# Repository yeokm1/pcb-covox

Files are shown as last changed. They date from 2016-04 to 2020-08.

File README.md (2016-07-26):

# pcb-covox
A tiny sound card based on the Covox Speech Thing design. I have another design which adds on an LM386 amplifier which can be found [here](https://github.com/yeokm1/pcb-covox-amp/).

##PCB Design software and addons used

1. Eagle 7.5.0: I use Standard but Light should still be able to open/modify the files.

##Images
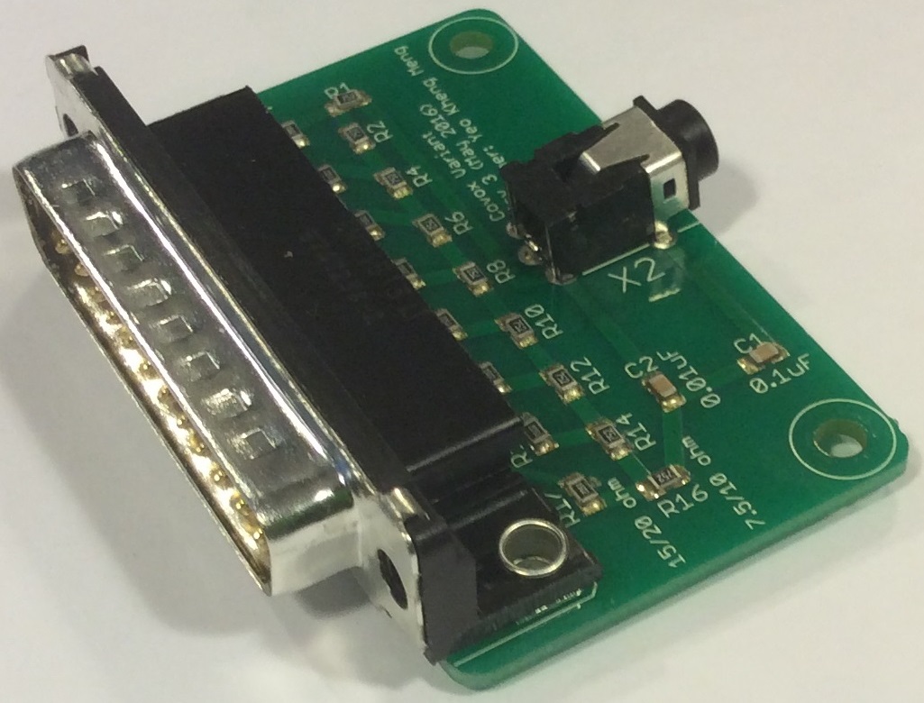
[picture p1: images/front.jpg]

This is a revision 3 board which has a bug in the mj2135 library which is a misaligned hole. I corrected this in Revision 4 but never actually fabricated that update.

Due to my oversight, only the DB25 pin 19 is grounded whearas the standard calls for pins 18-25 to be done so. You might need to modify the design if you face problems.

##Schematic drawings
Images are exported from Eagle at 600dpi.

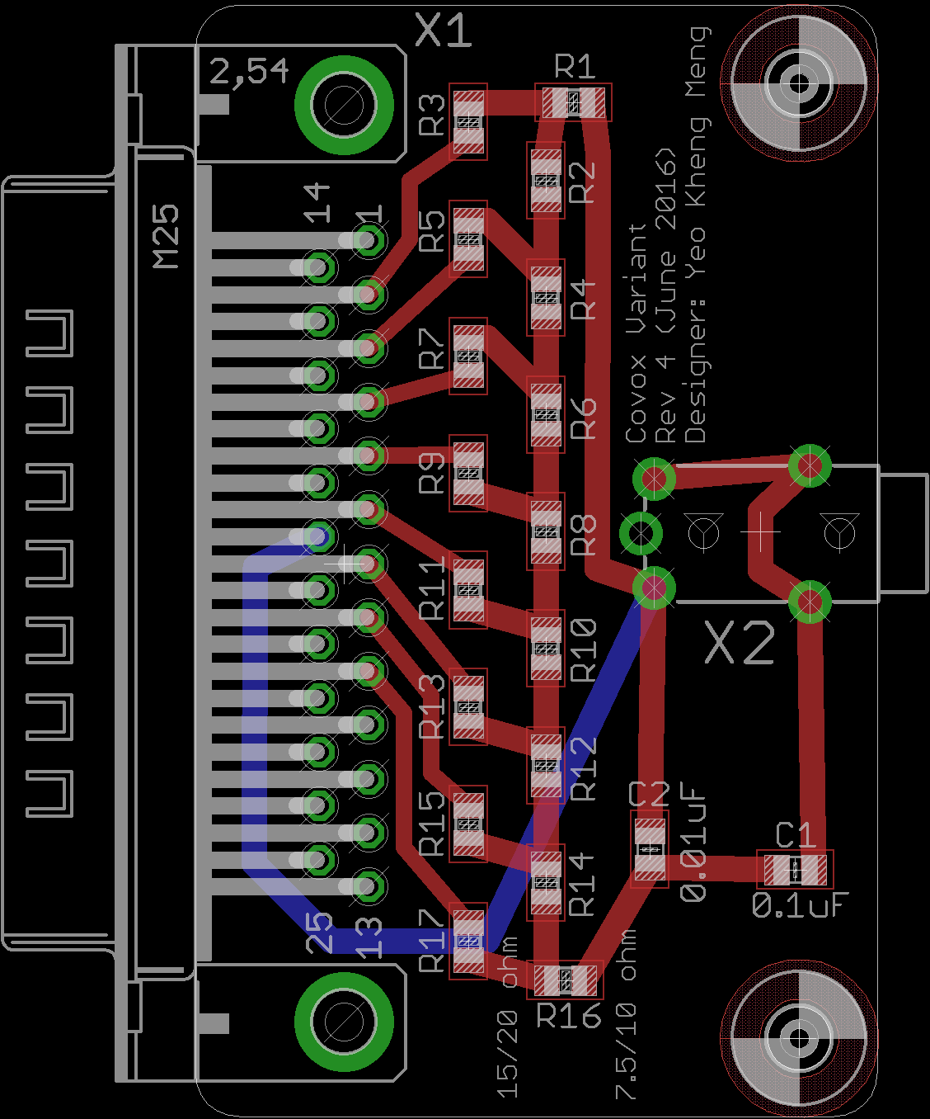
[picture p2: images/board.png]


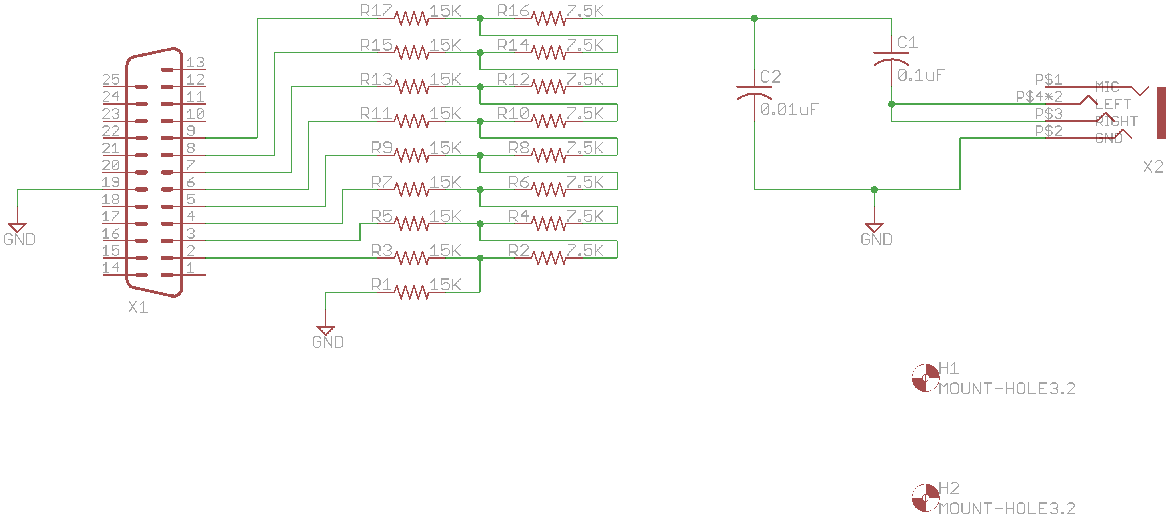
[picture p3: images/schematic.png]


##Parts required
Use Libreoffice to open [pcb-covox-bom.ods](pcb-covox-bom.ods)

##References
1. [Hardware implementation references](https://blog.frantovo.cz/c/307/DAC%20%28zvukov%C3%A1%20karta%29%20pro%20LPT%20port%20a.k.a.%20Covox)
2. [Design reference](http://kb.gr8bit.ru/KB0010/GR8BIT-KB0010-Adding-multimedia-capability-covox-device.html)
3. [MJ-2135 package obtained from coqui-dip](https://github.com/open-eie/coqui-dip)

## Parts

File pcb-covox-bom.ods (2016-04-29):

Parts | Value | Device | Package | Manufacturer | Part number | Qty | Unit Cost | Total Unit cost | Source webpage
X1 | DB-25 | Standard D Sub Connector, AMPLIMITE HD-20 Series, DB, Plug, 25, Steel Body, Through Hole | M-25HP | TE Connectivity | 5747238-2 | 1 | 5.07 | 5.07 | http://sg.element14.com/te-connectivity-amp/5747238-2/d-sub-connector-plug-25pos/dp/2452364
C2 | 0.01uF | SMD Multilayer Ceramic Capacitor, GRM Series | C0805 | Murata | GRM216R71H103JA01D | 1 | 0.065 | 0.065 | http://sg.element14.com/murata/grm216r71h103ja01d/cap-mlcc-x7r-10nf-50v-0805/dp/8820090
C1 | 0.1uF | SMD Multilayer Ceramic Capacitor, MCU Series | C0805 | Multicomp | MCU0805F104ZCT | 1 | 0.008 | 0.008 | http://sg.element14.com/multicomp/mcu0805f104zct/cap-mlcc-y5v-100nf-50v-0805/dp/9406409RL
R1, R3, R5, R7, R9, R11, R13, R15, R17 | 15K ohm, 0.5% | Surface Mount Chip Resistor, Thick Film, AEC-Q200 ERJ Series | R0805 | Panasonic Electronic Components | ERJ6RBD1502V | 9 | 0.047 | 0.423 | http://sg.element14.com/panasonic-electronic-components/erj6rbd1502v/res-thick-film-15k-0-5-0-1w-0805/dp/2380318
R2, R4, R6, R8, R10, R12, R14, R16 | 7.5K ohm, 0.5% | Thin Film, AEC-Q200 ERA Series | R0805 | Panasonic Electronic Components | ERA-6AED752V | 8 | 0.015 | 0.12 | http://sg.element14.com/panasonic-electronic-components/era-6aed752v/res-thin-film-7k5-0-5-0-125w-0805/dp/2407751
X2 | MJ-2135 | Phone Audio Connector, Socket, 3.5 mm, 4 Contacts | MJ-2135 | Pro Signal | MJ-2135 | 1 | 3.79 | 3.79 | http://sg.element14.com/pro-signal/mj-2135/connector-rca-jack-3-5mm-tht-4way/dp/1267377
- | HASL | PCB Fabrication | 5cm x 10cm | Elecrow | - | 1 | 7 | 7 | http://www.elecrow.com/5pcs-2-layer-pcb-p-1174.html
 |  |  |  |  |  |  | Subtotal | 16.476
 |  |  |  |  |  |  | GST 7% | 1.15332
 |  |  |  |  |  |  | Total (SGD) | 17.62932

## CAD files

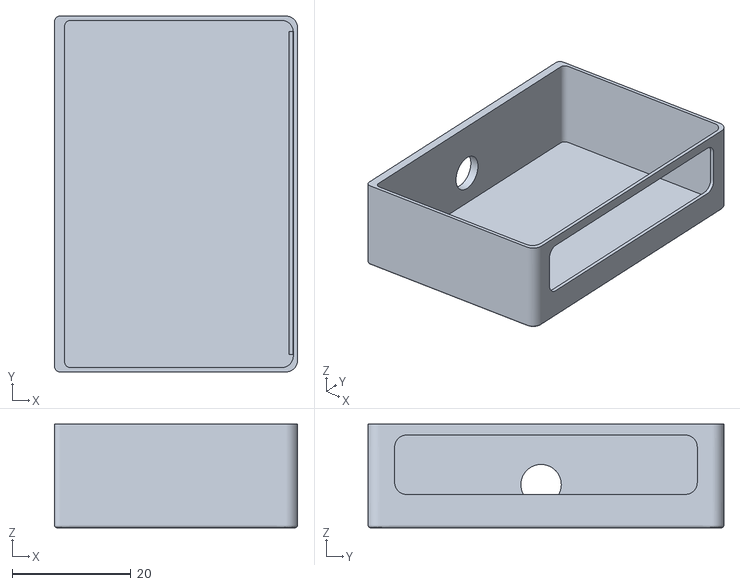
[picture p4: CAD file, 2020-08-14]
covox.stl
41.0 x 60.0 x 17.5

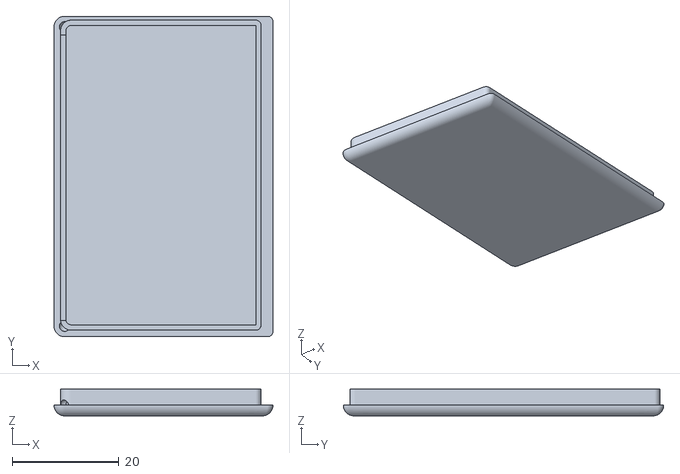
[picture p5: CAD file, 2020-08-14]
covox-top.stl
41.0 x 60.0 x 5.00

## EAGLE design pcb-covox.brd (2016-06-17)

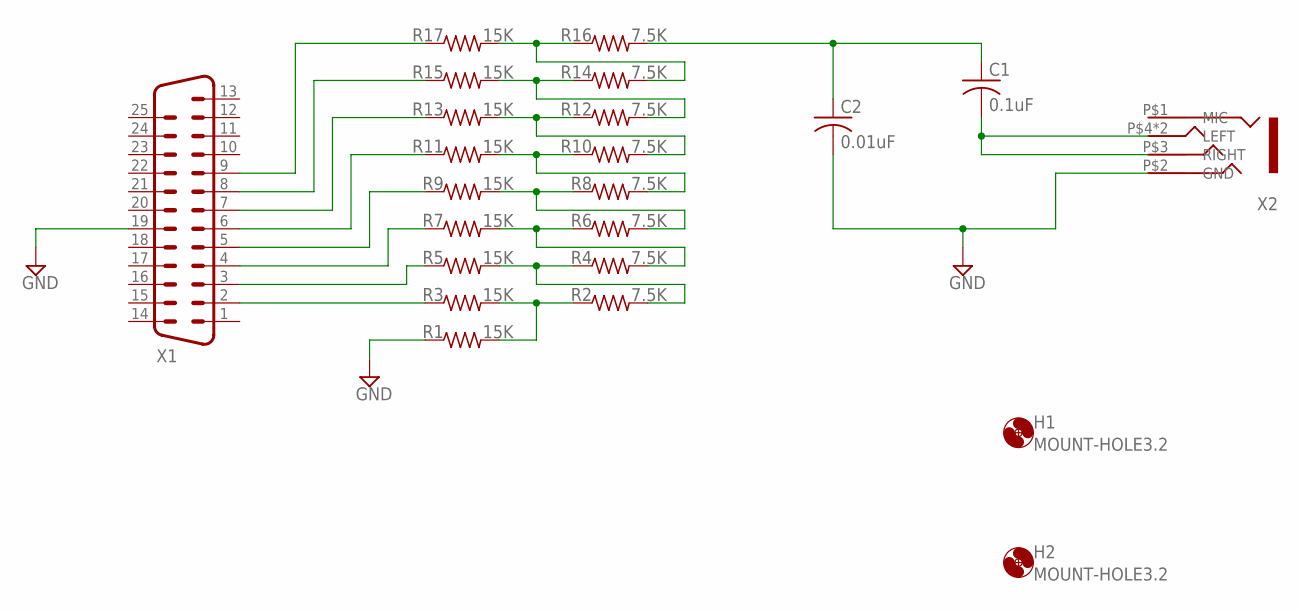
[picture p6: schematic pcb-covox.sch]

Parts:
C1: 0.1uF; C0805
C2: 0.01uF; C0805
H1, H2: MOUNT-HOLE3.2; 3,2
R1, R3, R5, R7, R9, R11, R13, R15, R17: 15K; R0805
R2, R4, R6, R8, R10, R12, R14, R16: 7.5K; R0805
X1: M25HP
X2: MJ-2135MJ-2135; MJ-2135

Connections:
GND: C2.2, R1.1, X1.19, X2.P$2 (GND)
unnamed: R3.1, X1.2
unnamed: R5.1, X1.3
unnamed: R7.1, X1.4
unnamed: R9.1, X1.5
unnamed: R11.1, X1.6
unnamed: R13.1, X1.7
unnamed: R15.1, X1.8
unnamed: R17.1, X1.9
unnamed: R1.2, R2.1, R3.2
unnamed: R2.2, R4.1, R5.2
unnamed: R4.2, R6.1, R7.2
unnamed: R6.2, R8.1, R9.2
unnamed: R8.2, R10.1, R11.2
unnamed: R10.2, R12.1, R13.2
unnamed: R12.2, R14.1, R15.2
unnamed: R14.2, R16.1, R17.2
unnamed: C1.1, C2.1, R16.2
unnamed: C1.2, X2.P$3 (RIGHT), X2.P$4 (LEFT), X2.P$5 (LEFT)

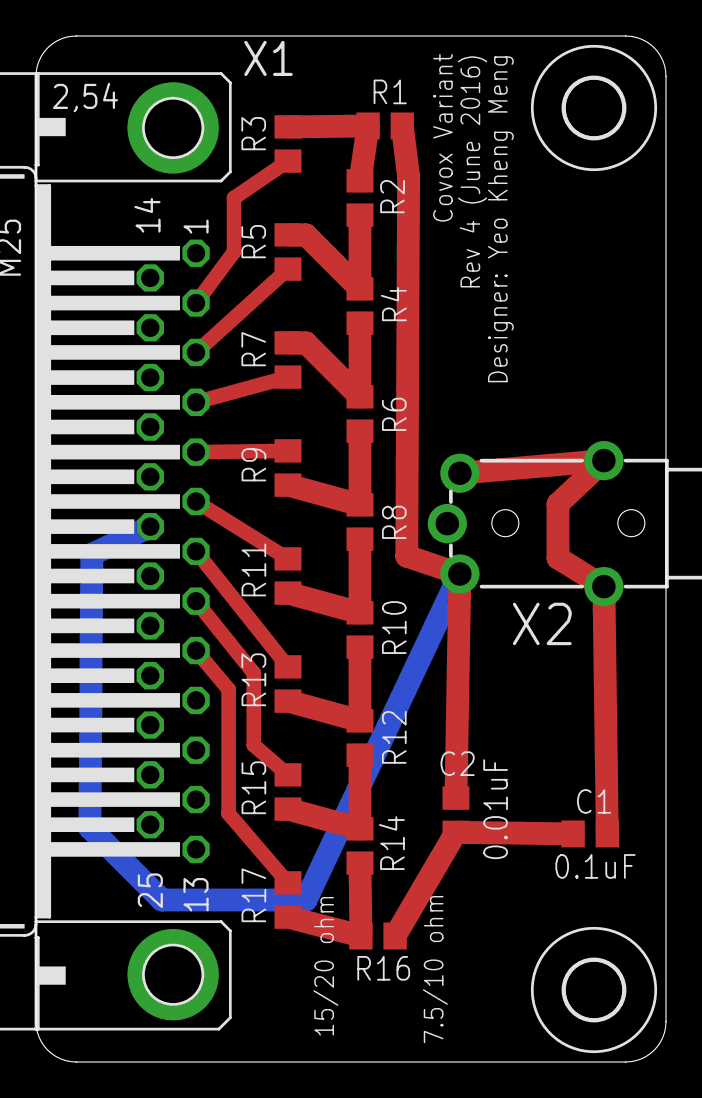
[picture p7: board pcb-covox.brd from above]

Board: 2 copper layers, 35.0 x 57.0 mm, 23 parts (0 on the bottom side), 19 nets.

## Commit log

2016-04-14 bom file
    [pcb-covox-bom.ods]
2016-04-27 corrected bug in size of audio connector
    [pcb-covox.brd, pcb-covox.sch]
2016-04-29 correct drc error
    [pcb-covox.brd]
2016-04-29 rev 2 gerber
2016-04-29 adjust MJ-2135 value
    [pcb-covox-bom.ods]
2016-05-09 updated error in mj 2135 library
    [pcb-covox.brd, pcb-covox.sch]
2016-05-09 rev 3 gerber
2016-05-09 change directory of gerber
2016-06-17 update error in mj2135 lbr
    [pcb-covox.brd, pcb-covox.sch]
2016-06-17 up to rev 4 for silkscreen
    [pcb-covox.brd]
2016-07-02 rev4 board image
2016-07-02 rev4 gerber
2020-06-18 3d print model
    [covox-top.stl, covox.stl]
